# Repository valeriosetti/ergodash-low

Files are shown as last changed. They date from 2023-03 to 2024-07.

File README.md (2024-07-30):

# What's this?

I've worked the ErgoDash keyboard for a while and it felt quite good, but it was a bit too
high for me. So I decided to design my own version in order to make it thinner.
Here's what I did:

- have all switches PCB mounted.
- do not use acrylic frame and let the PCB sit directly on the desktop.
- use low profile Gateron switches (KS-27).

In addition:

- I also added some holes at the corners of the board in order to make it
tiltable/adjustable with some screw.
- I replaced some of the pinky keys with 2u keycaps because my pinky's accuracy
is not really great.

## Kicad preview

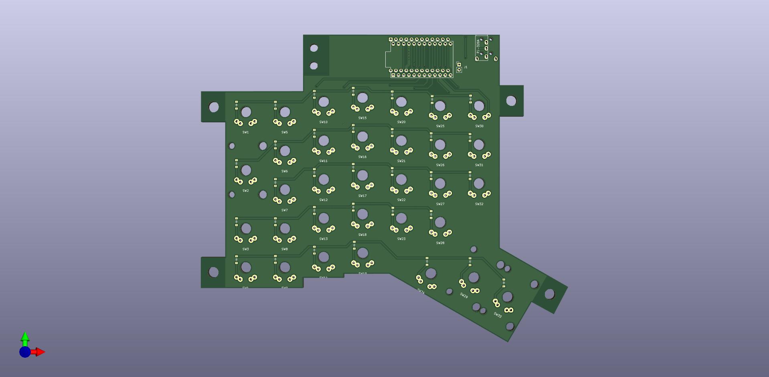
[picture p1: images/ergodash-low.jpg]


## Picture of the assembled board

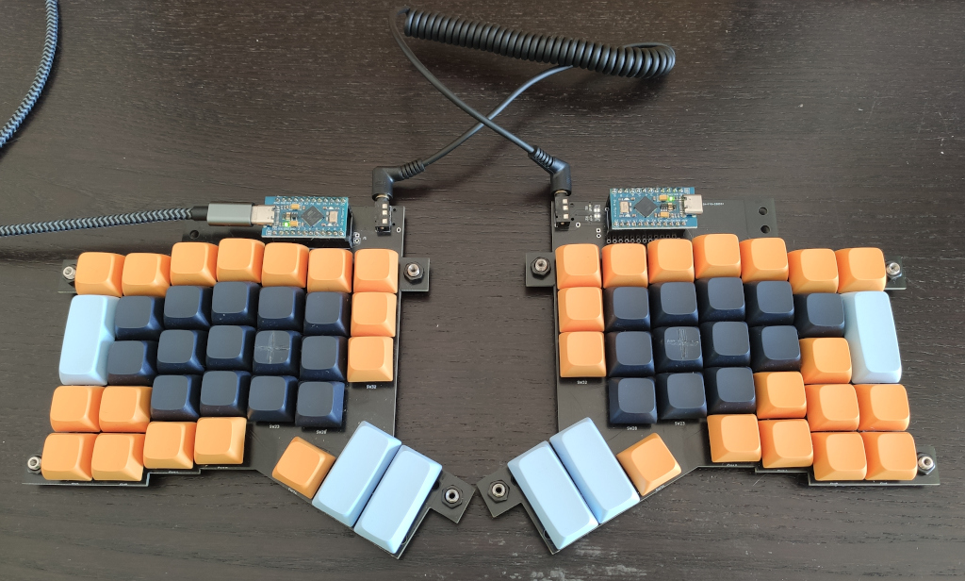
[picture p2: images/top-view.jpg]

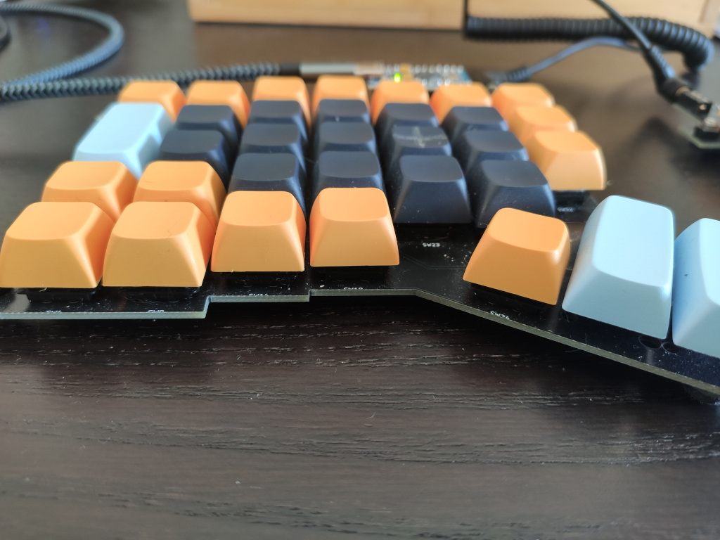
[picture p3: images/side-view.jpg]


# What's next?

I've been using this keyboard for more than a year now and I find it really
comfortable. There are still some improvements I would like to try though:

- make a new version with Kailh choch v1 keys in order to see if I can make
it even thinner than this.
- improve keys' position and perhaps also reduce the overall number:
    - central keys are not easily reachable with the index finger, so they
      might be lowered a bit in the layout.
    - 4 keys in the low-left row are too much (I currently have 2 Win-keys +
      Ctrl + Alt), so they can be reduced.

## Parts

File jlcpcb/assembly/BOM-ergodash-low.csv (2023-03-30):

Comment | Designator | Footprint | LCSC
D | D1,D10,D11,D12,D13,D14,D15,D16,D17,D18,D19,D2,D20,D21,D22,D23,D24,D25,D26,D27,D28,D29,D3,D30,D31,D32,D33,D4,D5,D6,D7,D8,D9 | D_SOD-123-reversible | C81598

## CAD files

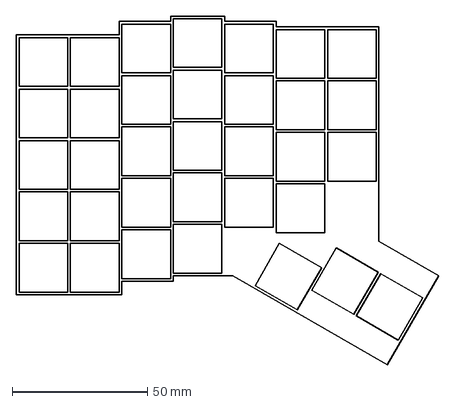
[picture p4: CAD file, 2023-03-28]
ergogen/switch_plate.dxf
156.1 x 129.0 mm

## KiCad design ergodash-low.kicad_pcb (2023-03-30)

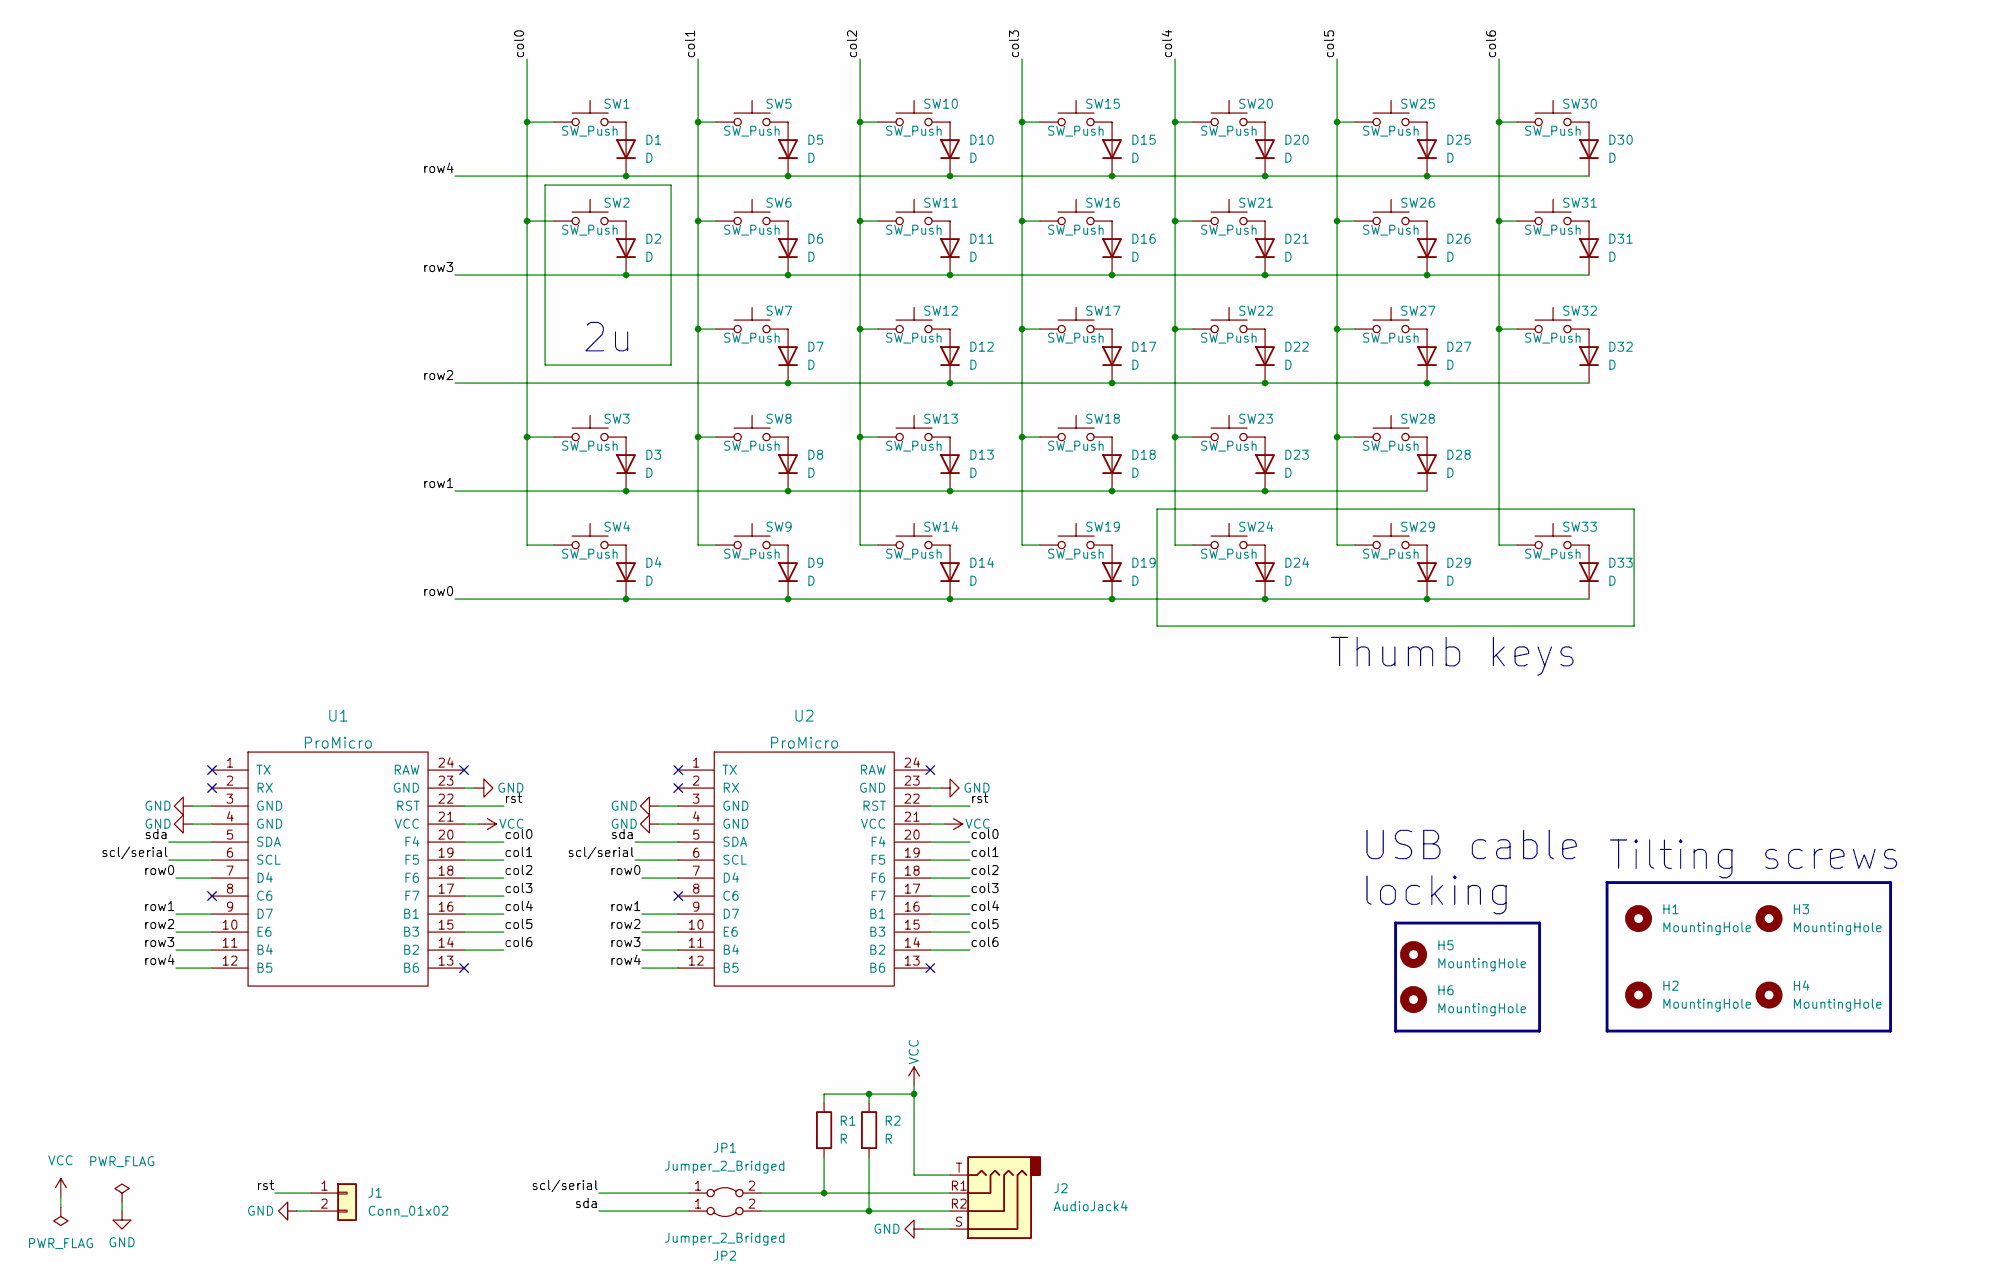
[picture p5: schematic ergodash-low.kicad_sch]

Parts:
D1, D2, D3, D4, D5, D6, D7, D8, D9, D10, D11, D12, D13, D14, D15, D16, D17, D18, D19, D20, D21, D22, D23, D24, D25, D26, D27, D28, D29, D30, D31, D32, D33: D; D_SOD-123-reversible
H1, H2, H3, H4: MountingHole; MountingHole_5.3mm_M5
H5, H6: MountingHole; MountingHole_4mm
J1: Conn_01x02; PinHeader_1x02_P2.54mm_Vertical
J2: AudioJack4; TRRS-PJ-320A-dual
JP1, JP2: Jumper_2_Bridged; SolderJumper-2_P1.3mm_Bridged_RoundedPad1.0x1.5mm
R1, R2: R; R_0603_1608Metric_Pad0.98x0.95mm_HandSolder
SW1, SW3, SW4, SW5, SW6, SW7, SW8, SW9, SW10, SW11, SW12, SW13, SW14, SW15, SW16, SW17, SW18, SW19, SW20, SW21, SW22, SW23, SW24, SW25, SW26, SW27, SW28, SW30, SW31, SW32: SW_Push; gateron_ks27_reversible
SW2, SW29, SW33: SW_Push; gateron_ks27_reversible_stabilizer
U1, U2: ProMicro

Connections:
/col0: SW1.1, SW2.1, SW3.1, SW4.1, U1.20 (F4), U2.20 (F4)
/col1: SW5.1, SW6.1, SW7.1, SW8.1, SW9.1, U1.19 (F5), U2.19 (F5)
/col2: SW10.1, SW11.1, SW12.1, SW13.1, SW14.1, U1.18 (F6), U2.18 (F6)
/col3: SW15.1, SW16.1, SW17.1, SW18.1, SW19.1, U1.17 (F7), U2.17 (F7)
/col4: SW20.1, SW21.1, SW22.1, SW23.1, SW24.1, U1.16 (B1), U2.16 (B1)
/col5: SW25.1, SW26.1, SW27.1, SW28.1, SW29.1, U1.15 (B3), U2.15 (B3)
/col6: SW30.1, SW31.1, SW32.1, SW33.1, U1.14 (B2), U2.14 (B2)
/row0: D4.1 (K), D9.1 (K), D14.1 (K), D19.1 (K), D24.1 (K), D29.1 (K), D33.1 (K), U1.7 (D4), U2.7 (D4)
/row1: D3.1 (K), D8.1 (K), D13.1 (K), D18.1 (K), D23.1 (K), D28.1 (K), U1.9 (D7), U2.9 (D7)
/row2: D7.1 (K), D12.1 (K), D17.1 (K), D22.1 (K), D27.1 (K), D32.1 (K), U1.10 (E6), U2.10 (E6)
/row3: D2.1 (K), D6.1 (K), D11.1 (K), D16.1 (K), D21.1 (K), D26.1 (K), D31.1 (K), U1.11 (B4), U2.11 (B4)
/row4: D1.1 (K), D5.1 (K), D10.1 (K), D15.1 (K), D20.1 (K), D25.1 (K), D30.1 (K), U1.12 (B5), U2.12 (B5)
/rst: J1.1, U1.22 (RST), U2.22 (RST)
/scl/serial: JP1.1 (A), U1.6 (SCL), U2.6 (SCL)
/sda: JP2.1 (A), U1.5 (SDA), U2.5 (SDA)
GND: J1.2, J2.S, U1.3 (GND), U1.4 (GND), U1.23 (GND), U2.3 (GND), U2.4 (GND), U2.23 (GND)
unnamed: D1.2 (A), SW1.2
unnamed: D2.2 (A), SW2.2
unnamed: D3.2 (A), SW3.2
unnamed: D4.2 (A), SW4.2
unnamed: D5.2 (A), SW5.2
unnamed: D6.2 (A), SW6.2
unnamed: D7.2 (A), SW7.2
unnamed: D8.2 (A), SW8.2
unnamed: D9.2 (A), SW9.2
unnamed: D10.2 (A), SW10.2
unnamed: D11.2 (A), SW11.2
unnamed: D12.2 (A), SW12.2
unnamed: D13.2 (A), SW13.2
unnamed: D14.2 (A), SW14.2
unnamed: D15.2 (A), SW15.2
unnamed: D16.2 (A), SW16.2
unnamed: D17.2 (A), SW17.2
unnamed: D18.2 (A), SW18.2
unnamed: D19.2 (A), SW19.2
unnamed: D20.2 (A), SW20.2
unnamed: D21.2 (A), SW21.2
unnamed: D22.2 (A), SW22.2
unnamed: D23.2 (A), SW23.2
unnamed: D24.2 (A), SW24.2
unnamed: D25.2 (A), SW25.2
unnamed: D26.2 (A), SW26.2
unnamed: D27.2 (A), SW27.2
unnamed: D28.2 (A), SW28.2
unnamed: D29.2 (A), SW29.2
unnamed: D30.2 (A), SW30.2
unnamed: D31.2 (A), SW31.2
unnamed: D32.2 (A), SW32.2
unnamed: D33.2 (A), SW33.2
unnamed: J2.R1, JP1.2 (B), R1.2
unnamed: J2.R2, JP2.2 (B), R2.2
VCC: J2.T, R1.1, R2.1, U1.21 (VCC), U2.21 (VCC)

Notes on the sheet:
USB cable locking
Tilting screws
Thumb keys

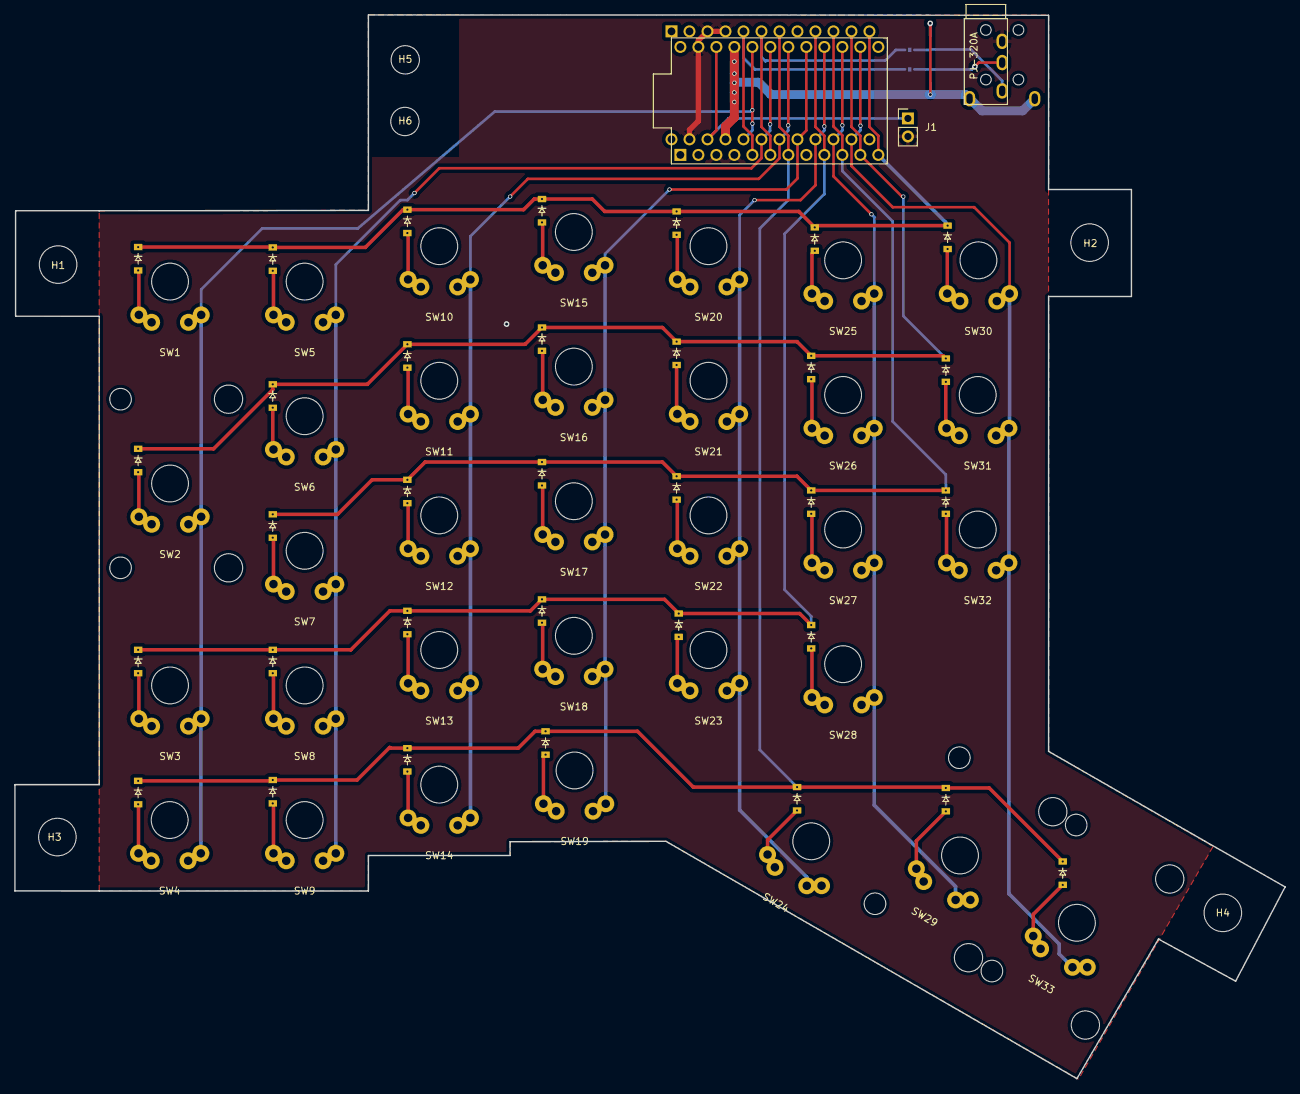
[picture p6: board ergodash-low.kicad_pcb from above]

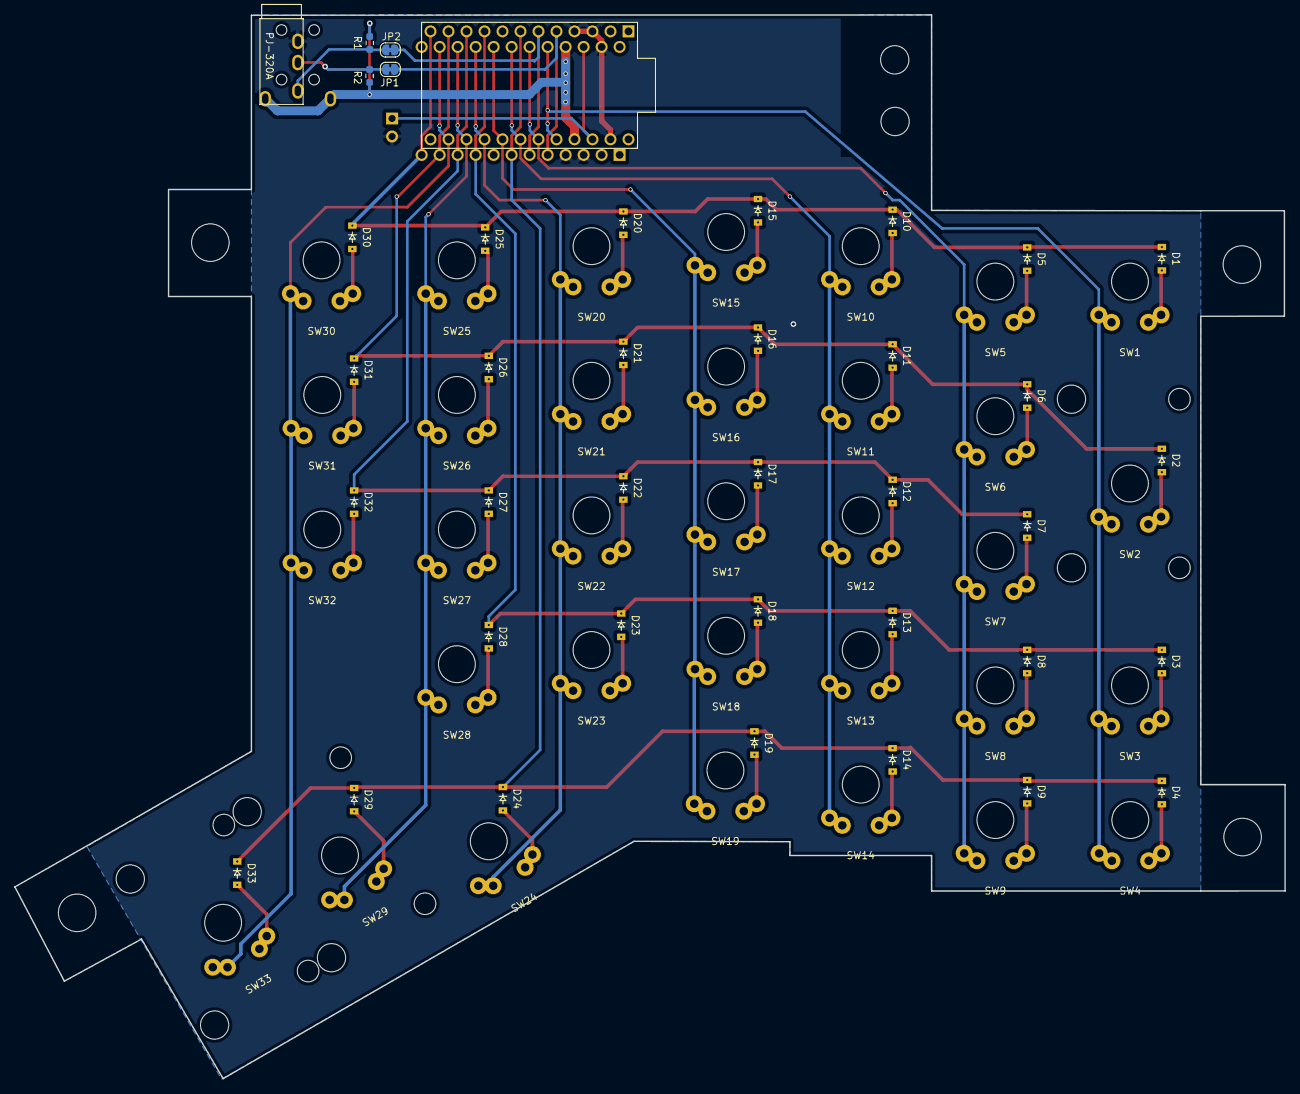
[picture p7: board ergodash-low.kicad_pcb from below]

Board: 2 copper layers, 179.3 x 150.1 mm, 80 parts (38 on the bottom side), 52 nets.

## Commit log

2023-03-28 adding ergogen source file and DXF
    [switch_plate.dxf]
2023-03-28 first version of schematic & pcb (to be finalized)
    [ergodash-low.kicad_pcb, ergodash-low.kicad_sch]
2023-03-30 removed unused libraries and updated footprints
2023-03-30 completed schematic and pcb
    [ergodash-low.kicad_pcb, ergodash-low.kicad_sch]
2023-03-30 adding gerber files for jlcpcb
    [BOM-ergodash-low.csv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]
2023-03-30 updated image of the board
2024-07-30 add gateron KS27 + kailh choc v1 combo footprint
